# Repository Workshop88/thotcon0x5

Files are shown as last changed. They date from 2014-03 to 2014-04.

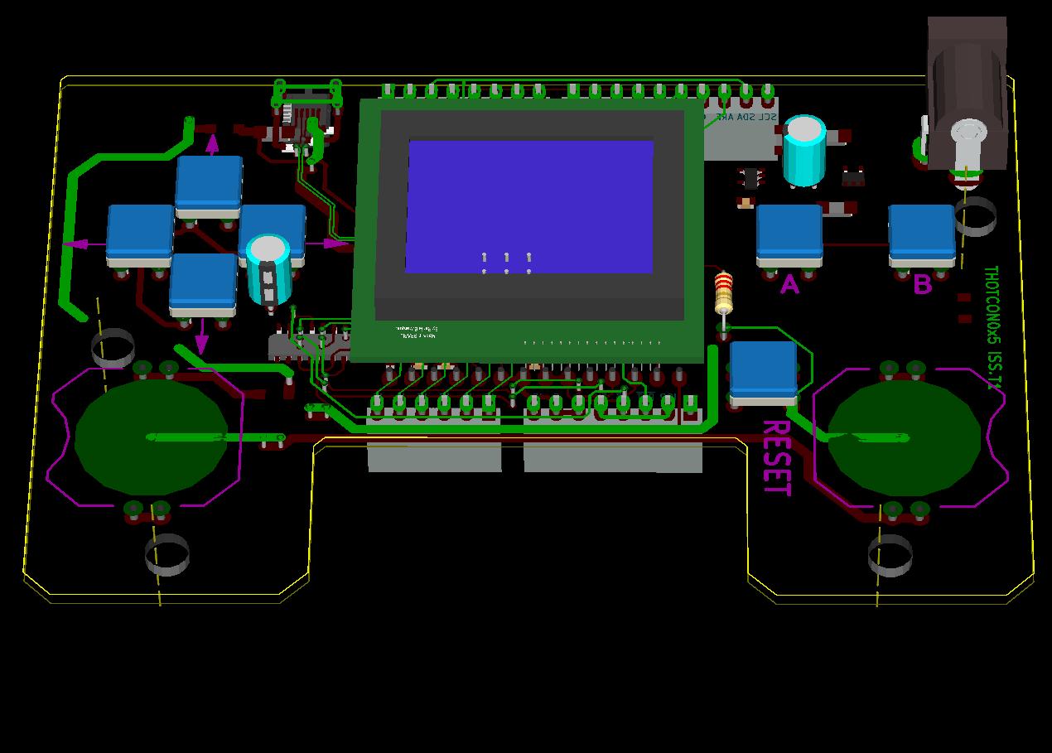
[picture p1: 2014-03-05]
hardware/attic/iss_T1/release/thotcon_user_perspective.jpg

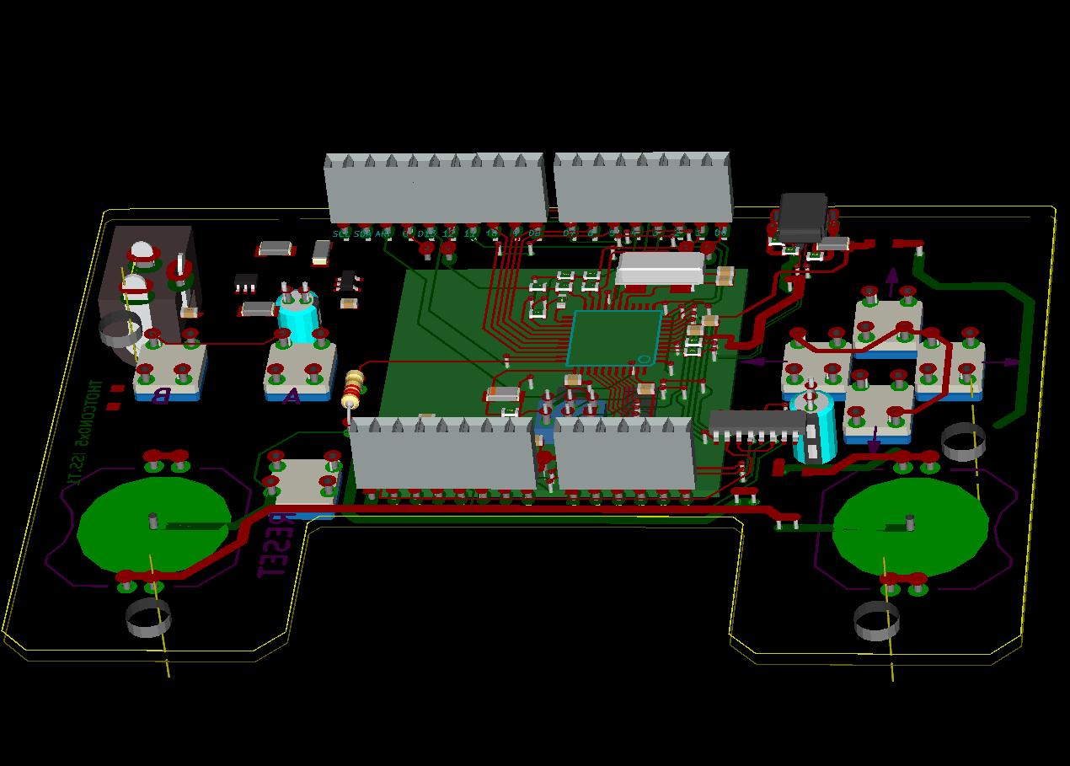
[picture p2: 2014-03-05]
hardware/attic/iss_T1/release/thotcon_perspective_bottom.jpg

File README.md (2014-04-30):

Thotcon 0x5 badges.

Basics:
* Replace ARDUINO_ROOT/hardware/arduino/variants/leonardo/pins_arduino.h with libraries/pins_arduino.h (back up the existing one)
* Replace ARDUINO_ROOT/hardware/arduino/boards.txt with the one from this repo.
* To program via USB, you need the actual Leonardo or LilyPadUSB bootloader.  To install that, you'll need to use some kind of AVRISP.  This is a good place to start: http://letsmakerobots.com/content/make-arduino-isp-programmer

More:
* The schematics are under hardware/development/iss_p1/release

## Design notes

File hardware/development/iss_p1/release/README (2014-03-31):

The files in this directory are in PDF format, and are provided as
a convenience. In the event of a discrepancy, the gerber files in the
"fab" directory will govern.

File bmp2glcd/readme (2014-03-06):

bmp2glcd - Bitmap to GLCD bitmap ver 1.01 by S.Varjo 2008

To create binary file simply invoke make. 

Usage: bmp2glcd <image.bmp> <options>
	-h <height>	target image height in pixels
	-w <width>	target image width in pixels
	-v	verbose mode
	-pgm	create header with __attribute__ ((progmem)) for AVR
	-pic30  create header whith __attribute__((space(auto_psv))) for PIC30
	-glcdlib create header for use with Arduino glcd library

This program converts a bitmap to binary bitmap (black and white) with 8bit page
height that can be written directly to graphical lcd display. A c-header file is
created where data bytes represent pixels in page columns rather than in lines.
The created bitmap is solely to see the result image in a simple way.

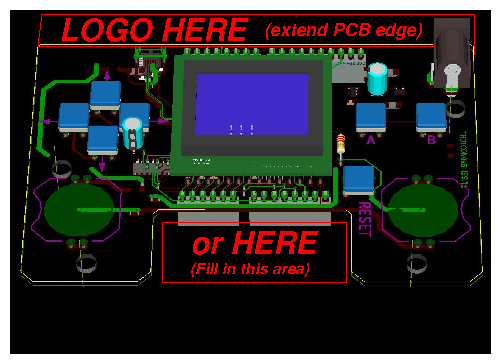
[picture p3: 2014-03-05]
hardware/attic/iss_T1/release/thotcon_label_view.png

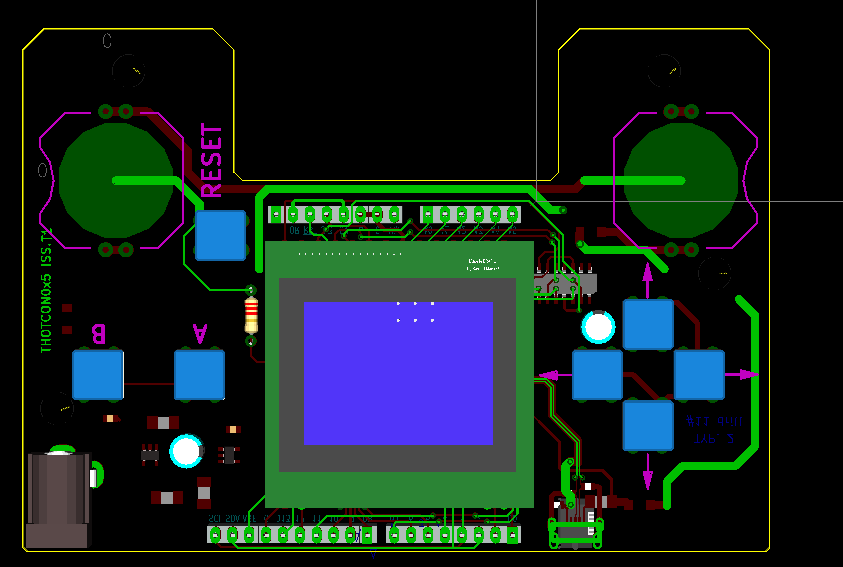
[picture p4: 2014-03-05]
hardware/attic/iss_T1/release/thotcon_0x5_display.png

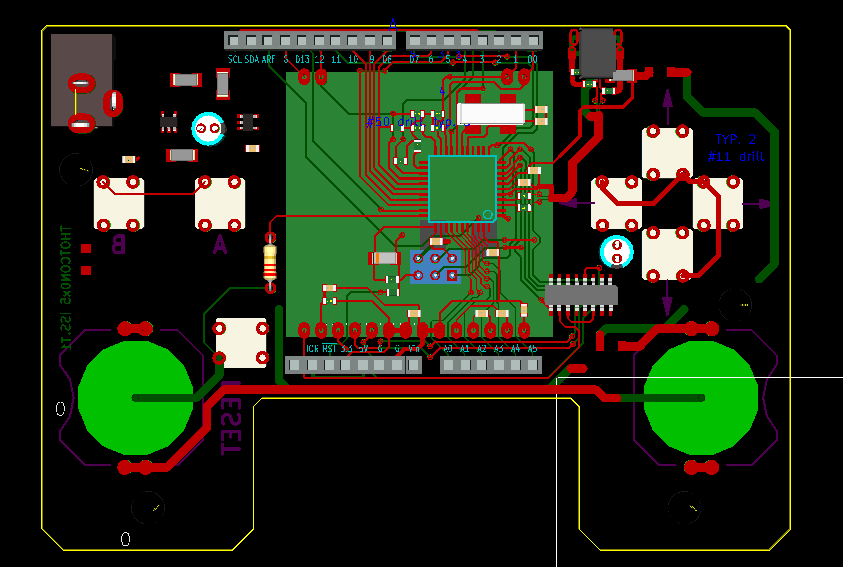
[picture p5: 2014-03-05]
hardware/attic/iss_T1/release/thotcon_0x5_bottom.png

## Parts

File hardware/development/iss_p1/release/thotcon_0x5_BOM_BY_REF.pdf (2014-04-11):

Sheet1
03/28/14 | ISSUE P1 | | PRINTED 032814 | | ISSUE P1 | | | ISSUE P1 | | ISSUE P1
REF. | VALUE | QTY. | DESCRIPTION | MFR | MFR_PN | PRICE EA @100 | EXT. | ASSY_STATUS | VENDOR 1 | VENDOR 2 | NOTES
B1,B2 | BATTERY | 2 | HOLDER BATT 2032 | LINX | BAT-HLD-001-THM | 0.27 | 0.54 | Y | Mous 712-BAT-HLD-001-THM | Digi BAT-HLD-001-THM-ND | Thru Hole
C2,C9,C11,C14,C15,C16 | 1 uF | 6 | CAP CER 0603 1uF 10% X7R | MURATA | GRM188R71E105KA12 | 0.061 | 0.366 | Y | TTI GRM188R71E105KA12 | Digi 490-5307-1-ND | 25 Volt
C3,C5,C7 | 4.7 uF | 3 | CAP CER 1206 4.7u 10% X7R | MURATA | GRM31CR71E475KA88L | 0.11 | 0.33 | Y | Mous 81-GRM31CR71E475KA88 | Digi 490-1809-1-ND | 25 Volt
C4,C6 | .01 uF | 2 | CAP CER 0603 .01 10% X7R | MURATA | GRM188R71C103KA01D | 0.02 | 0.04 | Y | Mous 81-GRM18R71C103KA01D | Digi 490-1525-1-ND | 16 Volt
C8,C17,C18,C19,C20 | .1 uF | 5 | CAP CER 0603 .1 10% X7R | MURATA | GRM188R71H104KA93 | 0.07 | 0.35 | Y | Mous 81-GRM188R71H104KA93 | Digi 490-1519-1-ND | 50 Volt
C12,C13 | 18 pF | 2 | CAP CER 0603 18 5% NPO | MURATA | GRM1885C1H180JA01D | 0.01 | 0.02 | Y | Mous 81-GRM39C180J50 | Digi 490-1409-1-ND | 25 Volt
D2,D4,D5 | MBR0530 | 3 | DIODE SCHTKY 20V | ON SEMI | MBR0530T1G | 0.06 | 0.18 | Y | NWK 83H7280 | Mous 863-MBR0530T1G
D6 | S01575 | 1 | DIODE SIG 75V SMD1206 | BOURNS | CD1206-S01575 | 0.04 | 0.04 | Y | Mous 652-CD1206-S01575 | Digi CD1206-S01575CT-ND
DS1 | LC DISPLAY | 1 | LCD GRPHIC 102x64 WHT | ELECT ASMBYS | DOGS102W-6 | 6.73 | 6.73 | Y | Mous 790-EADOGS102W-6
DS2 | “PARTY” | 1 | DIODE LED RED 1206 REV | KINGBRIGHT | APTR3216SURCK | 0.09 | 0.09 | Y | | Digi 754-1173-1-ND
F1 | .5 A | 1 | FUSE POLY 1206 .5A 15V | Littelfuse | 1206L050/15YR | 0.21 | 0.21 | Y | Mous 576-1206L050/15YR | Digi F3733CT-ND
J6 | USB_IN | 1 | CONN USB MICRO B THM | TE CONN / AMP | 2040002-1 | 1.29 | 1.29 | Y | Mous 604-APTR3216SURCK | Digi A108263CT-ND | Thru hole
R1 | 1K | 1 | RES CER 0603 1K 5% 1/10 | PANASONIC | ERJ3GEYJ102V | 0.006 | 0.01 | Y | Mous 667-ERJ-3GEYJ102V | Digi P1.0KGCT-ND
R2,R3 | 5V | 2 | VRSTR ESD 0603 LO-CAP | BOURNS | CG0603MLC-05E | 0.09 | 0.18 | Y | Mous 652-CG0603MLC-05E | Digi CG0603MLC-05ECT-ND
R4,R5 | 22 | 2 | RES CER 0603 22 5% 1/10 | PANASONIC | ERJ-3GEYJ220V | 0.003 | 0.005 | Y | Mous 667-ERJ-3GEYJ220V | Digi P220GCT-ND
R6,R16 | 120 | 2 | RES CER 0603 120 5% 1/10 | PANASONIC | ERJ-3GEYJ121V | 0.003 | 0.005 | Y | Mous 667-ERJ-3GEYJ121V | Digi P120GCT-ND
R7-R13 | 10K | 7 | RES CER 0603 10K 5% 1/10 | PANASONIC | ERJ-3GEYJ103V | 0.003 | 0.018 | Y | Mous 667-ERJ-3GEYJ103V | Digi P10KGCT-ND
R14 | 2.2K | 1 | RES CF AXIAL 2.2K 5% 1/8 | STACKPOLE | CF18JT2K20 | 0.02 | 0.02 | Y | Digi CF18JT2K20CT-ND
S1,S2 | RED | 2 | SW PB N.O. RED | TE CONN / AMP | 1825910-7 | 0.08 | 0.16 | Y | | Digi 450-1804-ND | RED
S3,S4,S5,S6,S7 | BLACK | 5 | SW PB N.O. BLACK | TE CONN / AMP | FSM4JH | 0.08 | 0.40 | Y | Mous 506-FSM4JH | Digi 450-1650-ND | BLACK
U1 | ATMEGA32U4 | 1 | IC MICROP AVR | ATMEL | ATMEGA32U4-AU | 3.67 | 3.67 | Y | NWK 68T2838 | Digi 535-11697-1-ND
U2 | 5V | 1 | IC VREG LDO 5V SOT23 | TI | LP2985-50DBVR | 0.23 | 0.23 | Y | Mous 595-LP2985-50DBVR | Digi 296-20717-1-ND
U3 | 3.3V | 1 | IC VREG LDO 3.3V SOT23 | TI | LP2985-33DBVR | 0.28 | 0.28 | Y | Mous 595-LP2985-33DBVR | Digi 296-18476-1-ND
U4 | MC14050 | 1 | IC LVL SHFTR HEX SOIC | ON SEMI | MC14050BDR2G | 0.15 | 0.15 | Y | Mous 863-MC14050BDR2G | Digi MC14050BDR2GOSCT-ND
Y1 | 8.000 MHz | 1 | XTAL 8 MHZ SMT | ABRACON | ABC2-8.000MHZ-4-T | 1.13 | 1.13 | Y | Mous 815-ABMM-16-B2-T | Digi 535-9155-1-ND
Z1,Z2 | 300 | 2 | IND FE 300 OHM | TDK | MMZ1608-B-301C | 0.02 | 0.04 | Y | Mous 810-MMZ1608B301C | Digi 445-2165-1-ND
| | | | | | SUB-TOTAL | 16.481

### NON-ITEMIZED

B1, B2 | CR2032 | 2 | BATTERY LI COIN 2032 | PANASONIC | CR2032 | 0.16 | 0.32 | Y
BOARD, PC | --- | 1 | DOUBLE SIDE | ****** ESTIMATED COST ******* | 4.00 | 4.00 | Y
| | | | | | PRODUCTION TOTAL | 20.80

### ADD-ON KIT

C1,C10 | 10 uF | 2 | CAP LYTIC RADIAL 10uF 20% | PANASONIC | ECEA1VKS100 | 0.06 | 0.12 | DO NOT PLACE | Mous 667-ECE-A1VKS100 | Digi P980-ND | 35 Volt
J1,J3 | 8 PIN | 2 | SOCKET STRP .1 1X8 | HARWIN | M20-7820842 | 0.55 | 1.10 | DO NOT PLACE | Mous 855-M20-7820842 | Digi 952-1823-ND
J2 | 6 PIN | 1 | SOCKET STRP .1 1X6 | HARWIN | M20-7820646 | 0.48 | 0.48 | DO NOT PLACE | Mous 855-M20-7820646 | Digi 952-1809-ND
J4 | 10PIN | 1 | SOCKET STRP .1 1X10 | HARWIN | M20-7821042 | 1.10 | 1.10 | DO NOT PLACE | Mous 855-M20-7821042 | Digi 952-1846-ND
J5 | EXT_POWER | 1 | JACK 2MM TAPER PIN | CUI | PJ-102A | 0.45 | 0.45 | DO NOT PLACE | Digi CP-102A-ND | FUTURE PJ-102A | Suffix H OK
| | | | | | Add-on SUBTOTAL | 3.25
| | | | | | WS88 BADGE TOTAL | 24.06

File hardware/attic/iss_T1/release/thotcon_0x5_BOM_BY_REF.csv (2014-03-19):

ref | value | Field1 | Field2 | Field3 | Field4 | Field5 | Field6 | Field7 | Field8 | Item count
B1,B2 | CR2032 | HOLDER BATT 2032 | LINX | BAT-HLD-001-THM | 0.27 | Y | Mous 712-BAT-HLD-001-THM | Digi BAT-HLD-001-THM-ND | Thru Hole | 2
C1 | 10 uF | CAP LYTIC RADIAL 10uF 20% | PANASONIC | ECEA1VKA100 | 0.11 | DO NOT PLACE | Mous 667-ECE-A1VKA100 | Digi P818-ND | 35 Volt | 1
C2 | 1 uF | CAP CER 0603 1uF 10% X7R | MURATA | GRM188R71E105KA12 | 0.061 | Y | TTI GRM188R71E105KA12 | Digi 490-5307-1-ND | 25 Volt | 1
C3 | 4.7 uF | CAP CER 1206 4.7u 10% X7R | MURATA | GRM31CR71E475KA88L | 0.11 | Y | Mous 81-GRM31CR71E475KA88 | Digi 490-1809-1-ND | 25 Volt | 1
C4 | .01 uF | CAP CER 0603 .01 10% X7R | MURATA | GRM188R71C103KA01D | 0.02 | Y | Mous 81-GRM18R71C103KA01D | Digi 490-1525-1-ND | 16 Volt | 1
C5 | 4.7 uF | CAP CER 1206 4.7u 10% X7R | MURATA | GRM31CR71E475KA88L | 0.11 | Y | Mous 81-GRM31CR71E475KA88 | Digi 490-1809-1-ND | 25 Volt | 1
C6 | .01 uF | CAP CER 0603 .01 10% X7R | MURATA | GRM188R71C103KA01D | 0.02 | Y | Mous 81-GRM18R71C103KA01D | Digi 490-1525-1-ND | 16 Volt | 1
C7 | 4.7 uF | CAP CER 1206 4.7u 10% X7R | MURATA | GRM31CR71E475KA88L | 0.11 | Y | Mous 81-GRM31CR71E475KA88 | Digi 490-1809-1-ND | 25 Volt | 1
C8 | .1 uF | CAP CER 0603 .1 10% X7R | MURATA | GRM188R71H104KA93 | 0.07 | Y | Mous 81-GRM188R71H104KA93 | Digi 490-1519-1-ND | 50 Volt | 1
C9 | 1 uF | CAP CER 0603 1uF 10% X7R | MURATA | GRM188R71E105KA12 | 0.061 | Y | TTI GRM188R71E105KA12 | Digi 490-5307-1-ND | 25 Volt | 1
C10 | 10 uF | CAP LYTIC RADIAL 10uF 20% | PANASONIC | ECEA1VKA100 | 0.11 | Y | Mous 667-ECE-A1VKA100 | Digi P818-ND | 35 Volt | 1
C11 | 1 uF | CAP CER 0603 1uF 10% X7R | MURATA | GRM188R71E105KA12 | 0.061 | Y | TTI GRM188R71E105KA12 | Digi 490-5307-1-ND | 25 Volt | 1
C12,C13 | 18 pF | CAP CER 0603 18 5% NPO | MURATA | GRM1885C1H180JA01D | 0.01 | Y | Mous 81-GRM39C180J50 | Digi 490-1409-1-ND | 25 Volt | 2
C14..C16 | 1 uF | CAP CER 0603 1uF 10% X7R | MURATA | GRM188R71E105KA12 | 0.061 | Y | TTI GRM188R71E105KA12 | Digi 490-5307-1-ND | 25 Volt | 3
C17..C20 | .1 uF | CAP CER 0603 .1 10% X7R | MURATA | GRM188R71H104KA93 | 0.07 | Y | Mous 81-GRM188R71H104KA93 | Digi 490-1519-1-ND | 50 Volt | 4
D2..D5 | MBR0530 | DIOD SCHTKY 20V | ON SEMI | MBR0530T1G | 0.06 | Y | NWK 83H7280 | Mous 863-MBR0530T1G |  | 3
D6 | S01575 | DIODE SIG 75V SMD1206 | BOURNS | CD1206-S01575 | 0.04 | Y | Mous 652-CD1206-S01575 | Digi CD1206-S01575CT-ND |  | 1
DS1 | EA_DOGS102 | LCD GRPHIC 102x64 WHT | ELECT ASSMBYS | DOGS102W-6 | 6.73 | Y | Mous 790-EADOGS102W-6 |  |  | 1
F1 | .5 A | FUSE POLY 1206 .5A 15V | Littelfuse | 1206L050/15YR | 0.21 | Y | Mouser 576-1206L050/15YR | Digikey F3733CT-ND |  | 1
J1 | POWER | SOCKET STRP .1 1X8 | HARWIN | M20-7820842 | 0.55 | DO NOT PLACE | Mous 855-M20-7820842 | Digi 952-1823-ND |  | 1
J2 | ANALOG | SOCKET STRP .1 1X6 | HARWIN | M20-7820646 | 0.48 | DO NOT PLACE | Mous 855-M20-7820646 | Digi 952-1809-ND |  | 1
J3 | DIGITAL_0 | SOCKET STRP .1 1X8 | HARWIN | M20-7820842 | 0.55 | DO NOT PLACE | Mous 855-M20-7820842 | Digi 952-1823-ND |  | 1
J4 | DIGITAL_1 | SOCKET STRP .1 1X10 | HARWIN | M20-7821042 | 1.104 | DO NOT PLACE | Mous 855-M20-7821042 | Digi 952-1846-ND |  | 1
J5 | EXT_POWER | JACK 2MM TAPER PIN | CUI | PJ-102A | 0.45 | DO NOT PLACE | Digi CP-102A-ND | FUTURE PJ-102A | Suffix H OK | 1
J6 | USB_IN | CONN USB MICRO B THM | TE | 2040002-1 | 1.99 | Y | Digi A108263CT-ND |  |  | 1
MH1..MH4 | TOOLING | TOOLING | P/O PCB |  |  |  |  |  |  | 4
P2 | ICSP | TEST PORT | P/O PCB |  |  |  |  |  |  | 1
R2,R3 | 5V | VRSTR ESD 0603 LO-CAP | BOURNS | CG0603MLC-05E | 0.09 | Y | Mous 652-CG0603MLC-05E | Digi CG0603MLC-05ECT-ND |  | 2
R4,R5 | 22 | RES CER 0603 22 5% 1/10 | PANASONIC | ERJ-3GEYJ220V | 0.003 | Y | Mous 667-ERJ-3GEYJ220V | Digi P220GCT-ND |  | 2
R6 | 120 | RES CER 0603 120 5% 1/10 | PANASONIC | ERJ-3GEYJ121V | 0.003 | Y | Mous 667-ERJ-3GEYJ121V | Digi P120GCT-ND |  | 1
R7..R13 | 10K | RES CER 0603 10K 5% 1/10 | PANASONIC | ERJ-3GEYJ103V | 0.003 | Y | Mous 667-ERJ-3GEYJ103V | Digi P10KGCT-ND |  | 7
R14 | 2.2K | RES CF AXIAL 2.2K 5% 1/8 | STACKPOLE | CF18JT2K20 | 0.02 | DO NOT PLACE | Digi CF18JT2K20CT-ND |  |  | 1
R16 | 10K | RES CER 0603 10K 5% 1/10 | PANASONIC | ERJ-3GEYJ103V | 0.003 | Y | Mous 667-ERJ-3GEYJ103V | Digi P10KGCT-ND |  | 1
S1 | A | SW PB N.O. | OMRON | B3F-1000 | 0.35 | Y | Mous 653-B3F-1000 | Digi SW400-ND |  | 1
S2 | B | SW PB N.O. | OMRON | B3F-1000 | 0.35 | Y | Mous 653-B3F-1000 | Digi SW400-ND |  | 1
S3 | RST | SW PB N.O. | OMRON | B3F-1000 | 0.35 | Y | Mous 653-B3F-1000 | Digi SW400-ND |  | 1
S4 | UP | SW PB N.O. | OMRON | B3F-1000 | 0.35 | Y | Mous 653-B3F-1000 | Digi SW400-ND |  | 1
S5 | RGT | SW PB N.O. | OMRON | B3F-1000 | 0.35 | Y | Mous 653-B3F-1000 | Digi SW400-ND |  | 1
S6 | DWN | SW PB N.O. | OMRON | B3F-1000 | 0.35 | Y | Mous 653-B3F-1000 | Digi SW400-ND |  | 1
S7 | LFT | SW PB N.O. | OMRON | B3F-1000 | 0.35 | Y | Mous 653-B3F-1000 | Digi SW400-ND |  | 1
U1 | ATMEGA32U4 | IC MICROP AVR | ATMEL | ATMEGA32U4-AU | 3.96 | Y | NEWARK 68T2838 | Digi 535-11697-1-ND |  | 1
U2 | 5V | IC VREG LDO 5V SOT23 | TI | LP2985-50DBVR | 0.23 | Y | Mous 595-LP2985-50DBVR | Digi 296-20717-1-ND |  | 1
U3 | 3.3V | IC VREG LDO 3.3V SOT23 | TI | LP2985-33DBVR | 0.28 | Y | Mous 595-LP2985-33DBVR | Digi 296-18476-1-ND |  | 1
U4 | MC14050 | IC LVL SHFTR HEX SOIC | ON SEMI | MC14050BDR2G | 0.15 | Y | Mous 863-MC14050BDR2G | Digi MC14050BDR2GOSCT-ND |  | 1
Y1 | 8.000 MHz | XTAL 8 MHZ SMT | ABRACON | ABC2-8.000MHZ-4-T | 1.13 | Y | Mous 815-ABMM-16-B2-T | Digi 535-9155-1-ND |  | 1
Z1,Z2 | 300 | IND FE 300 OHM | TDK | MMZ1608-B-301C | 0.02 | Y | Mous 810-MMZ1608B301C | Digi 445-2165-1-ND |  | 2

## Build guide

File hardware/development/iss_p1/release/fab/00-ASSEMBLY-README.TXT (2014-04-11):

FILE:  00-ASSEMBLY-README.TXT 

April 11 2014 rev. P1

CHANGES:

    1.  Do not place white tape on "gold" and red boards.
    2.  Do not put white tape on DS1. Delete white tape from BOM.
    3.  (4a) Do not remove manufacturer stickers from display.
    4.  ADD Note A, Red and black switches.

Project: "Thotcon0x5 Badge Project" - An electric name tag.

Customer: Workshop 88, Inc.
Engineer: Paul Reich <reichp@att.net> -- 630-924-7289.
Project Manager: Rudy Ristich <rudy@workshop88.com>

Client: Thotcon 0x5 Organizing Committee.

NOTES:

   A.  Place RED switches at S1 and S2.  Place BLACK switches at
       S3, S4, S5, S6, & S7. Failure to do is a visual defect.

   1.  Please advise ASAP as to the suitability of the enclosed
       files, particularly the centroid file (thotcon_0x5-all.pos),
       should any file conversions be required.
       
   2.  A quantity of parts sufficient to assemble a minimum of 850
       units will be delivered for assembly.
       
       Over-runs, scrap, and leftover material must be returned.
       Please return unpopulated PCBs and panels as well.

   3.  Manufacture each of the following colors as follows:

        SOLDER MASK         SILKSCREEN        Quantity
   
       Gloss "gold"           BLACK           8 minimum
       Gloss red              BLACK          40   "
       Gloss blue             WHITE          40   "
       Gloss green            WHITE         128   "
       Flat black             WHITE         608   "
                                            ____________
                              GRAND TOTAL   824 minimum

   4.  DS1 - Glass display:
           Glass display DS1 must be fixtured such that the under-
           side of the display is spaced .04" - .07" above the PCB
           surface.  Failure to do so is a DEFECT that will leave
           the displays susceptible to mechanical and thermal stress
           and breakage.

   5.  There are a several unused components on each assembly. These
       components are designated "DO NOT PLACE" or "P/O PCB" on the
       bill of material. Holes for "DO NOT PLACE" components must
       remain free of solder.

   6.  Battery holders must be positioned with opening (cutout) as
       shown on the silkscreen.
       
   7.  Build ALL GOLD and RED panels FIRST. Build ALL GREEN and BLUE
       panels next. Build the BLACK panels LAST. These panels are
       the most numerous. Shortfalls here can be accommodated more
       readily.
       
   8.  Finished goods must be packaged in a manner sufficient to
       protect against ESD hazards & breakage of the (glass) display
       unit. Antistat bags or antistat bubble wrap are acceptable.
       Like colors must be packaged or grouped together. 
       
   9.  Customer will install batteries and program units.

  10.  Completed units and other materials, as noted in (2) and (3)
       will be retrieved by the customer (or his agent) at your Elk
       Grove Village location.

********************************************************************

           -----------  FILE MANIFEST  ------------------

File name                                      Description
------------------------------------------------------------------
00-ASSEMBLY-README.1ST                    This file

thotcon_0x5-all.pos                       SMD pick and place file.
thotcon_0x5-F_Paste.gtp                   SMD side paste mask, Gerber
thotcon_0x5-B_SilkS-MIRROR.pdf            Through-hole silk, PDF (mirrored)
thotcon_0x5-Dwgs_User.pdf                 PCB Fab/Assembly dwg, PDF.
thotcon_0x5-F_SilkS.pdf                   SMD-side silkscreen PDF

REFERENCE:

File name                                      Description
----------------------------------------------------------------------
thotcon_0x5_SCHEM-A.pdf                  "A" size schematic, PDF format
thotcon_0x5_SCHEM-B.pdf                  "B" size (11x17) schematic, PDF
thotcon_0x5_BOM_BY_REF.pdf                Bill of material, PDF
thotcon_0x5-drl.rpt                       Drill report, text

thotcon_0x5-F_copper.pdf                  Front copper, PDF
thotcon_0x5-B_copper.pdf                  Back copper, PDF

thotcon_0x5-F_Mask.pdf                    Front mask, PDF
thotcon_0x5-B_Mask.pdf                    Back mask, PDF

04-01-2014 Thotcon0X5 Issue P1 release

EOF

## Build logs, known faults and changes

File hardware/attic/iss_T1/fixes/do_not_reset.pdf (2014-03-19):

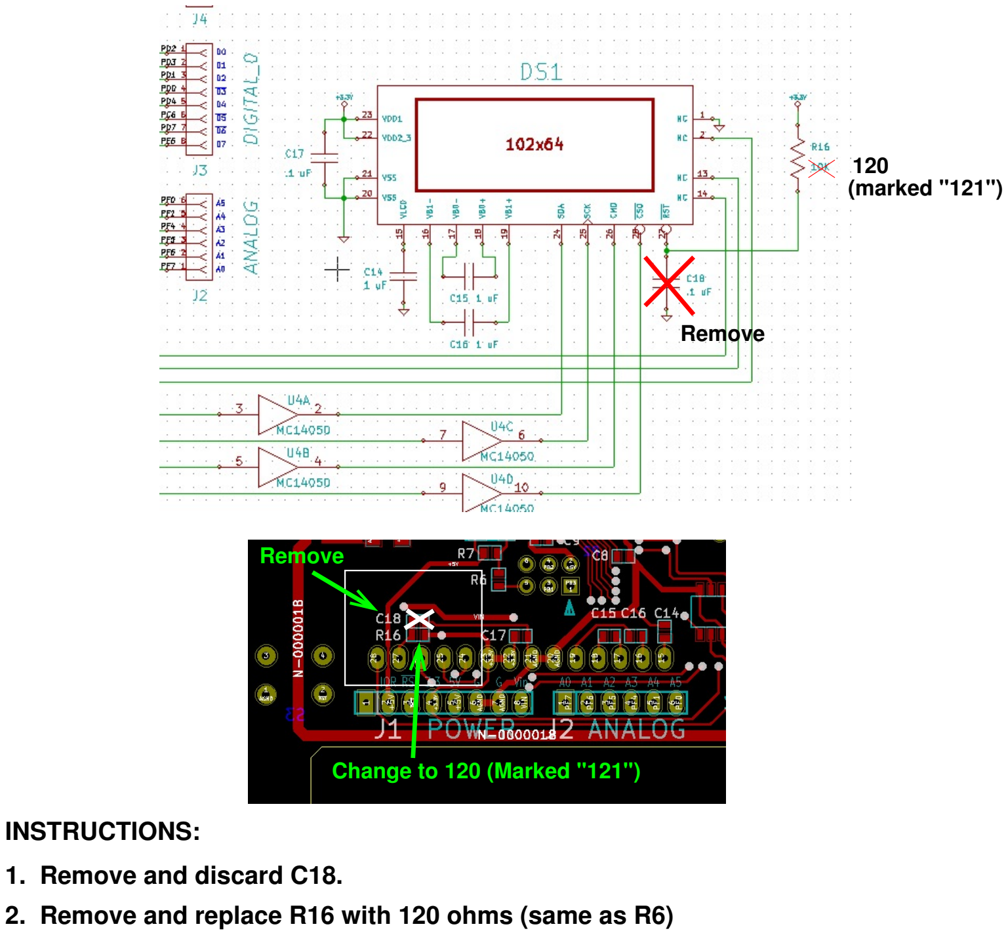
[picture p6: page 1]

120
(marked "121")

Remove

Remove

Change to 120 (Marked "121")

1. Remove and discard C18.

INSTRUCTIONS:

### 2. Remove and replace R16 with 120 ohms (same as R6)

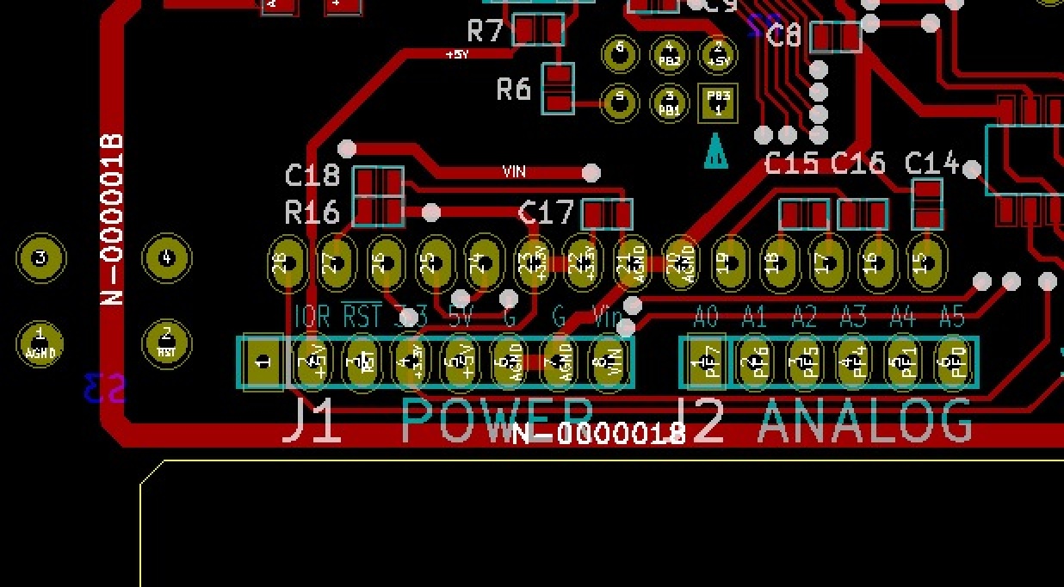
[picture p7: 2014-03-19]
hardware/attic/iss_T1/fixes/reset_3.jpg

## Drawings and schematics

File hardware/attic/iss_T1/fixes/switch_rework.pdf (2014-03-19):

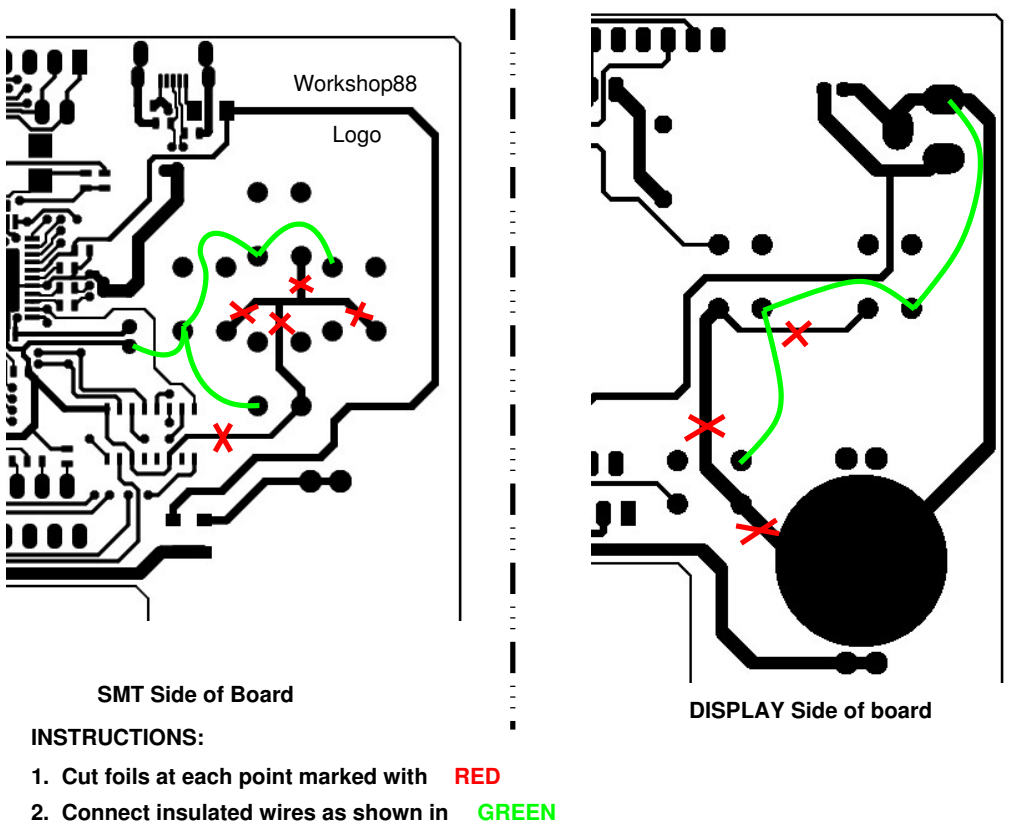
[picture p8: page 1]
Workshop88; Logo; GREEN; RED

SMT Side of Board

DISPLAY Side of board

INSTRUCTIONS:
1. Cut foils at each point marked with
2. Connect insulated wires as shown in

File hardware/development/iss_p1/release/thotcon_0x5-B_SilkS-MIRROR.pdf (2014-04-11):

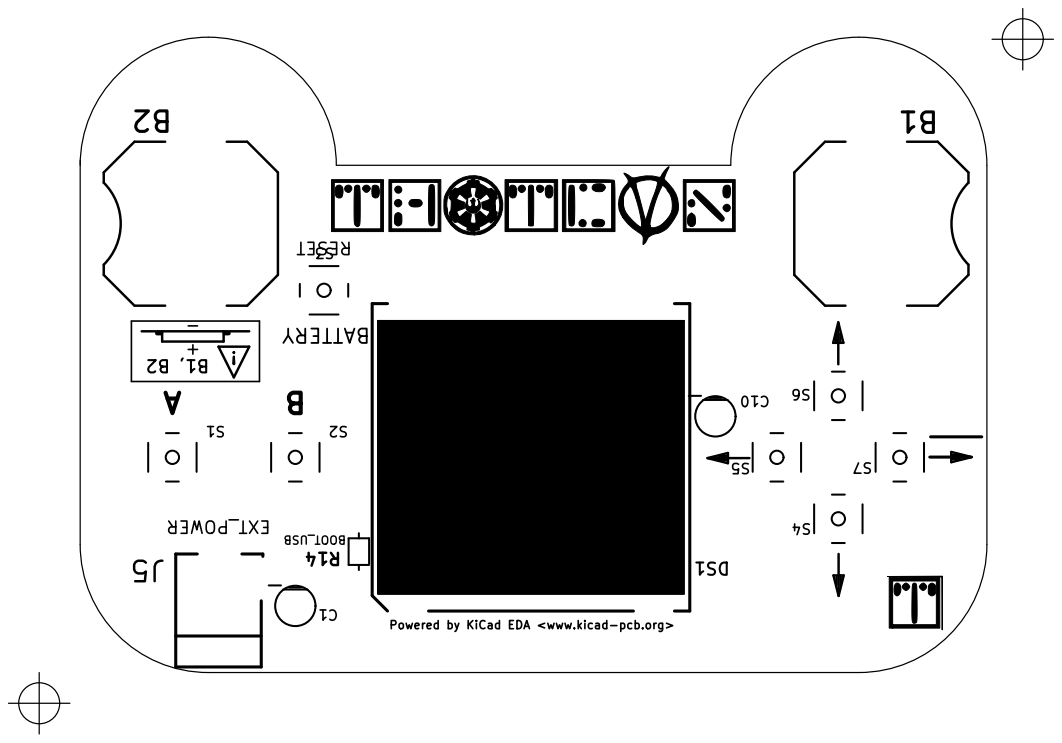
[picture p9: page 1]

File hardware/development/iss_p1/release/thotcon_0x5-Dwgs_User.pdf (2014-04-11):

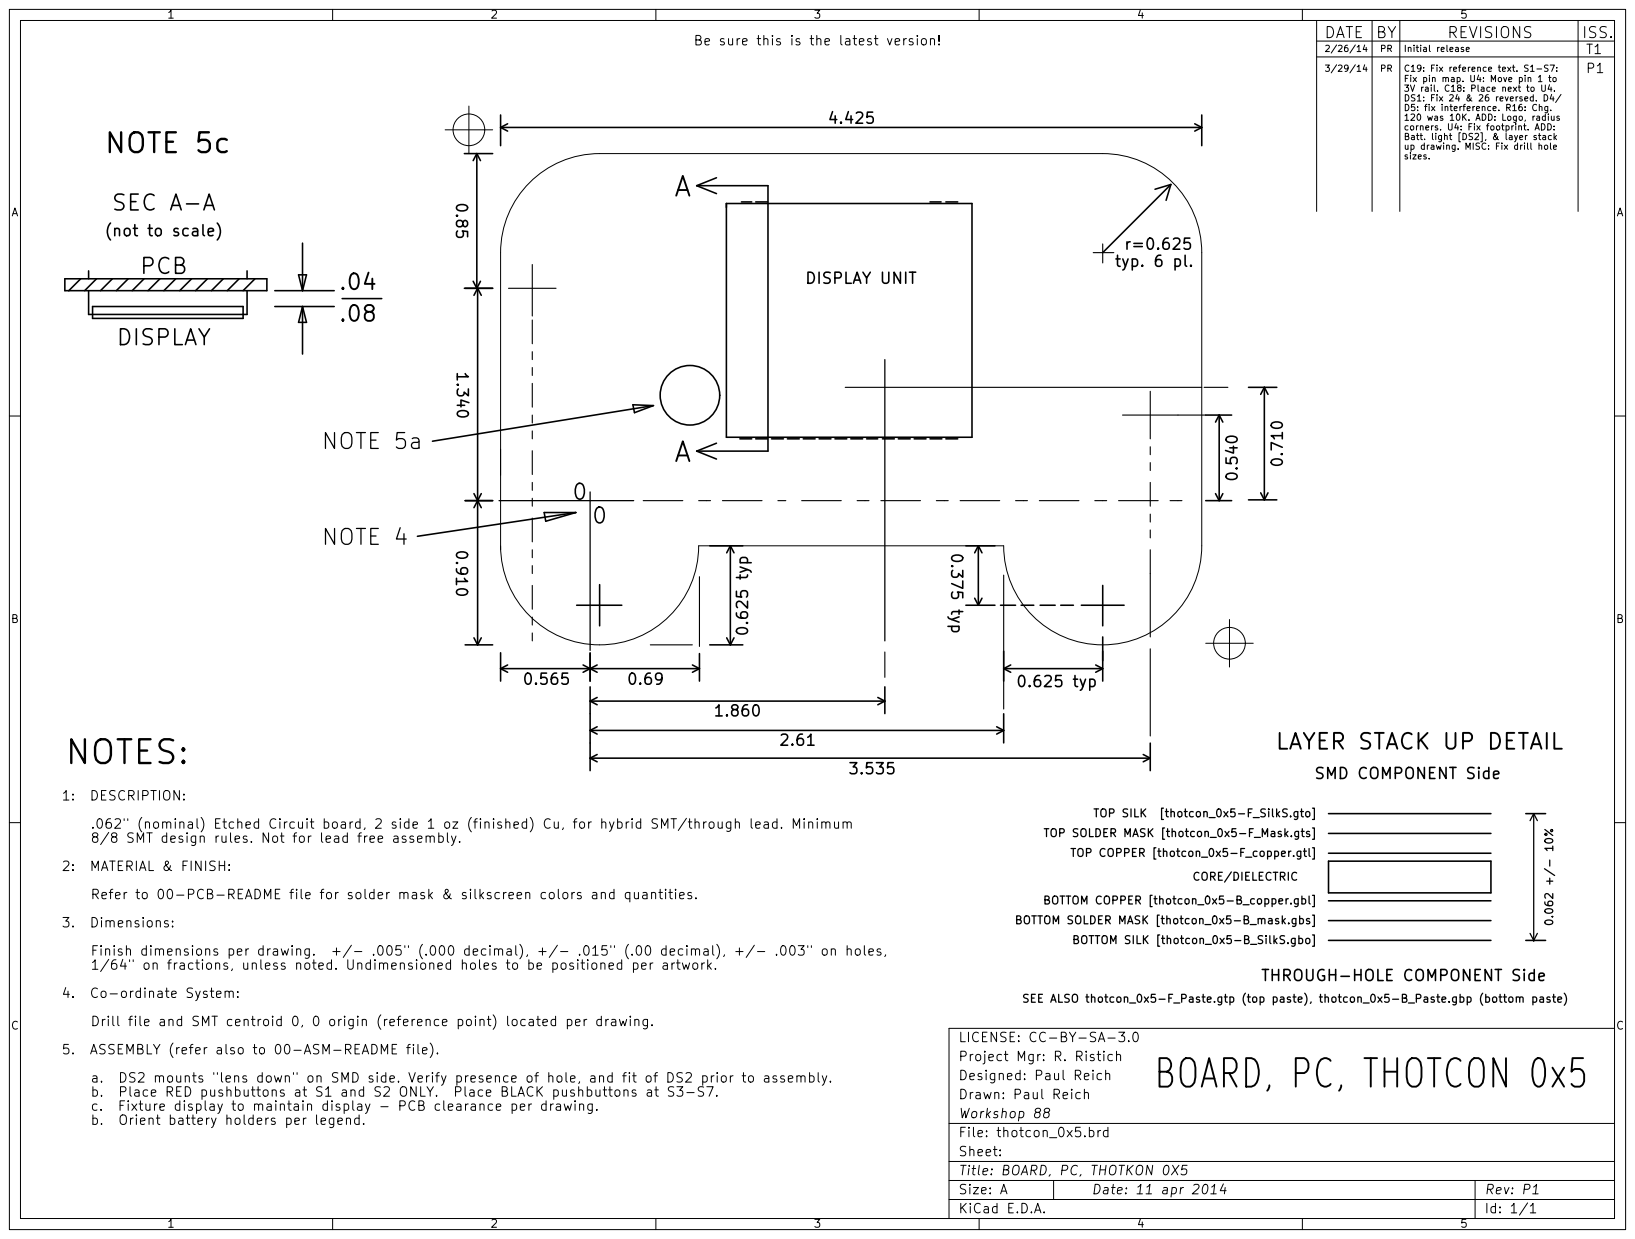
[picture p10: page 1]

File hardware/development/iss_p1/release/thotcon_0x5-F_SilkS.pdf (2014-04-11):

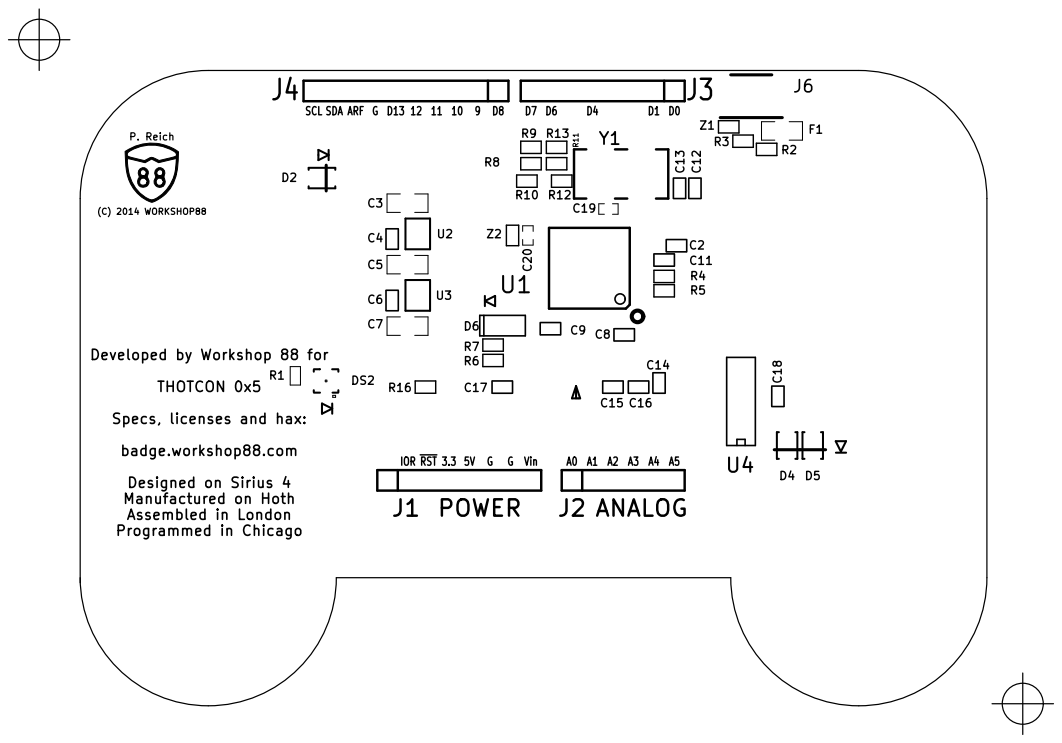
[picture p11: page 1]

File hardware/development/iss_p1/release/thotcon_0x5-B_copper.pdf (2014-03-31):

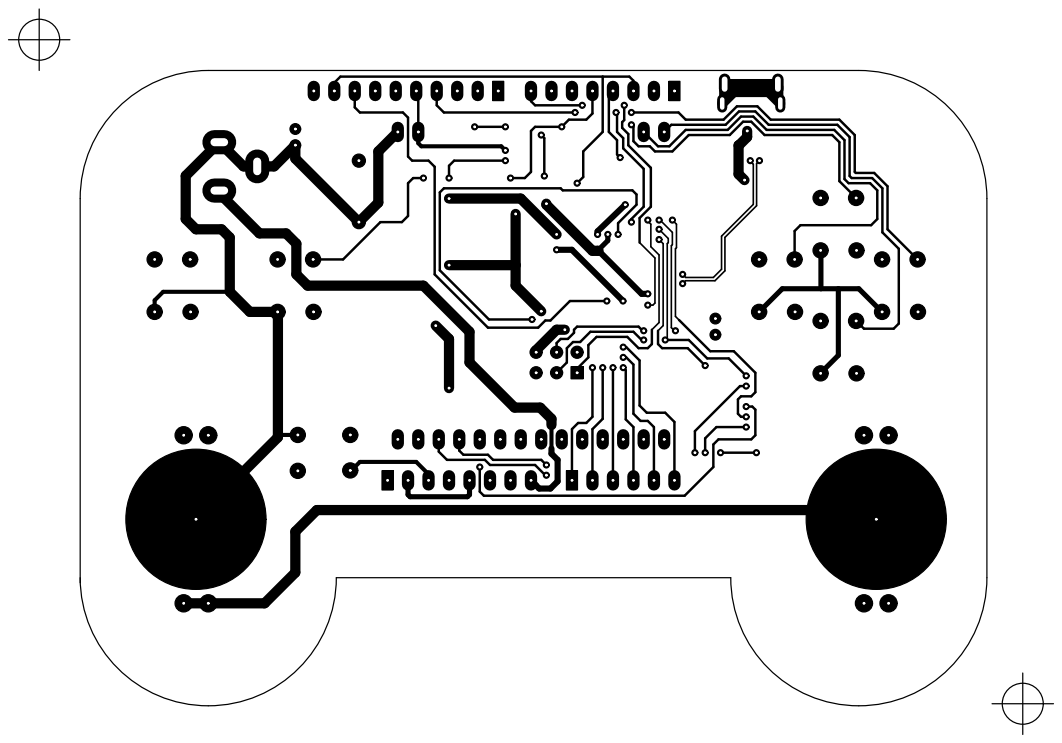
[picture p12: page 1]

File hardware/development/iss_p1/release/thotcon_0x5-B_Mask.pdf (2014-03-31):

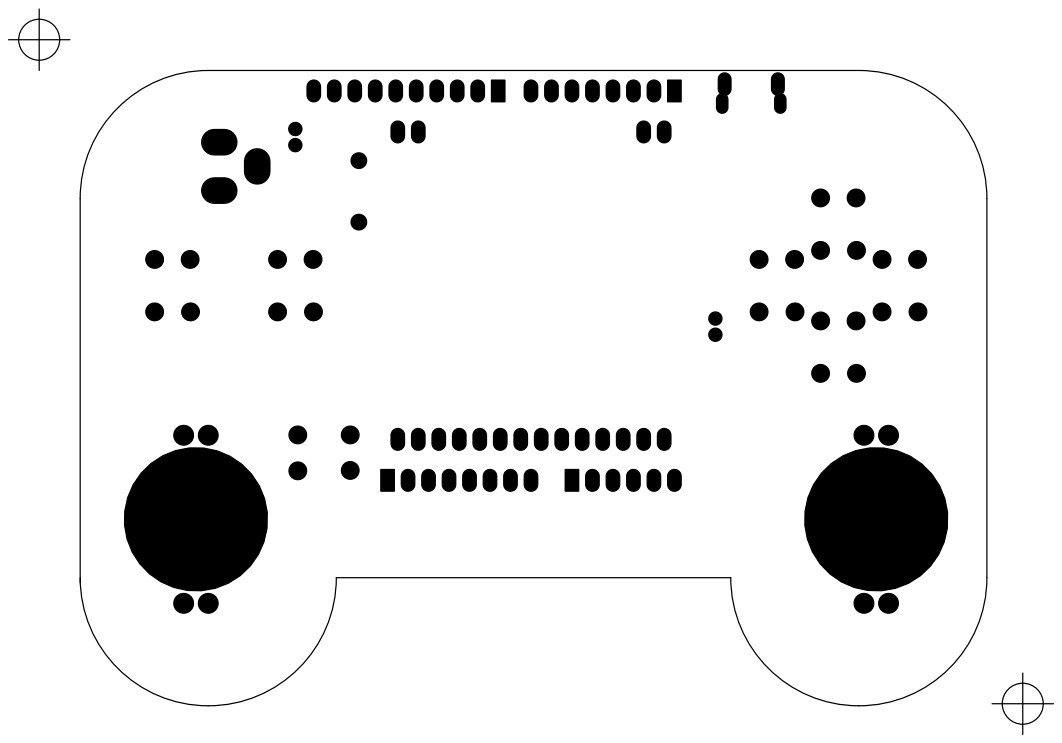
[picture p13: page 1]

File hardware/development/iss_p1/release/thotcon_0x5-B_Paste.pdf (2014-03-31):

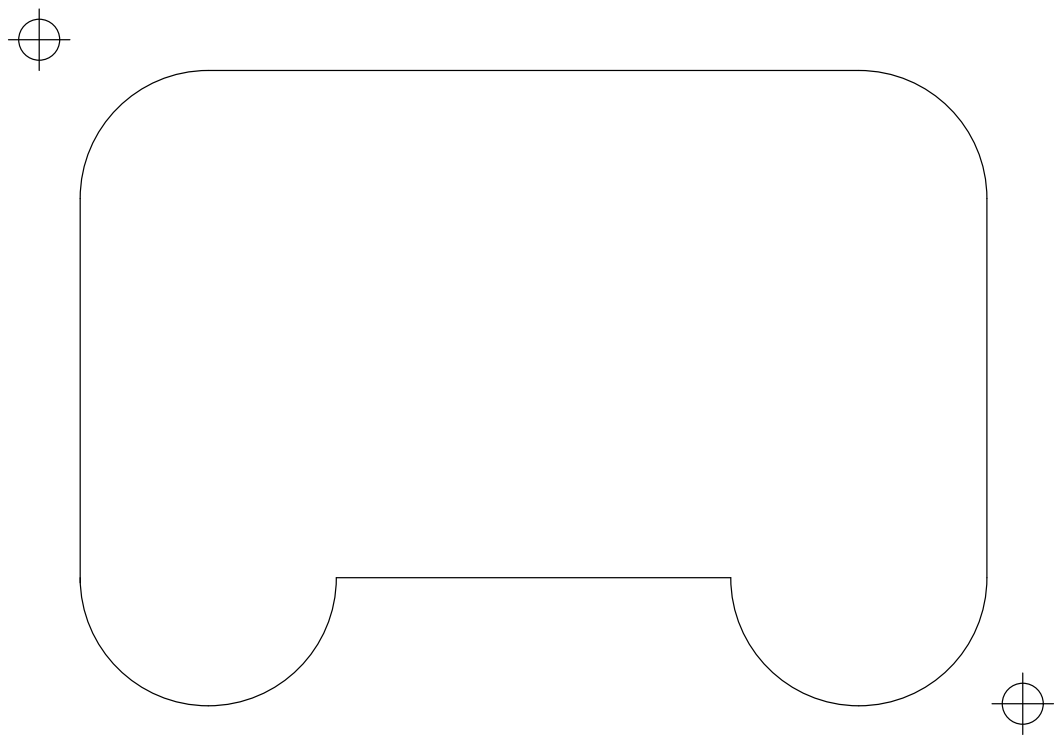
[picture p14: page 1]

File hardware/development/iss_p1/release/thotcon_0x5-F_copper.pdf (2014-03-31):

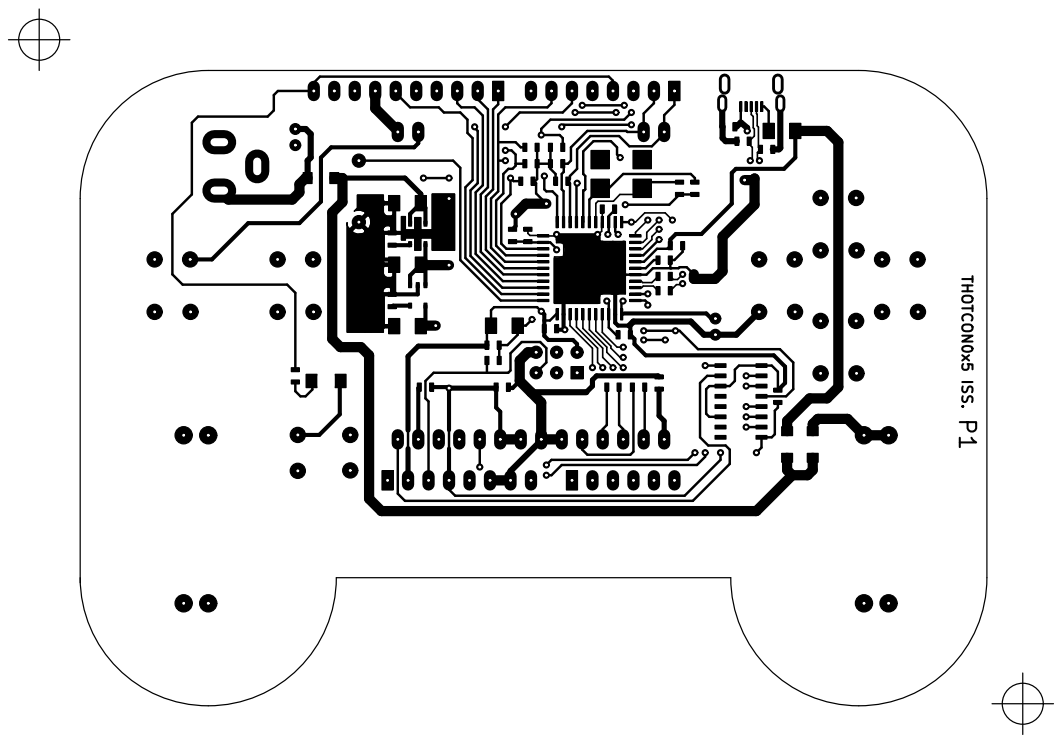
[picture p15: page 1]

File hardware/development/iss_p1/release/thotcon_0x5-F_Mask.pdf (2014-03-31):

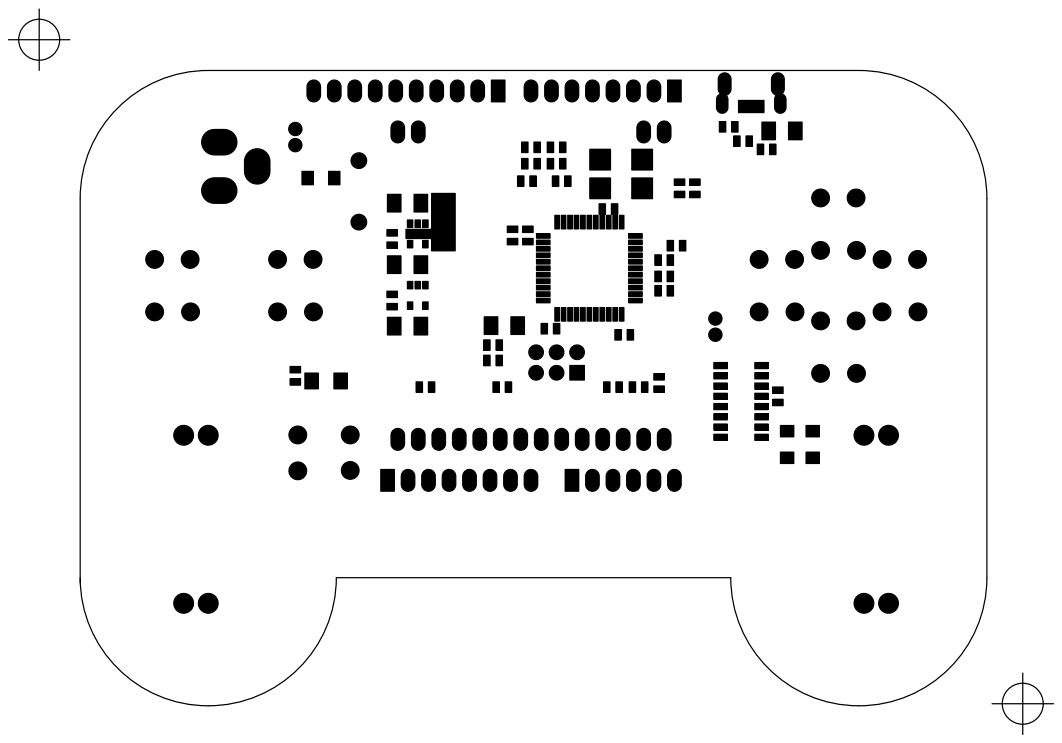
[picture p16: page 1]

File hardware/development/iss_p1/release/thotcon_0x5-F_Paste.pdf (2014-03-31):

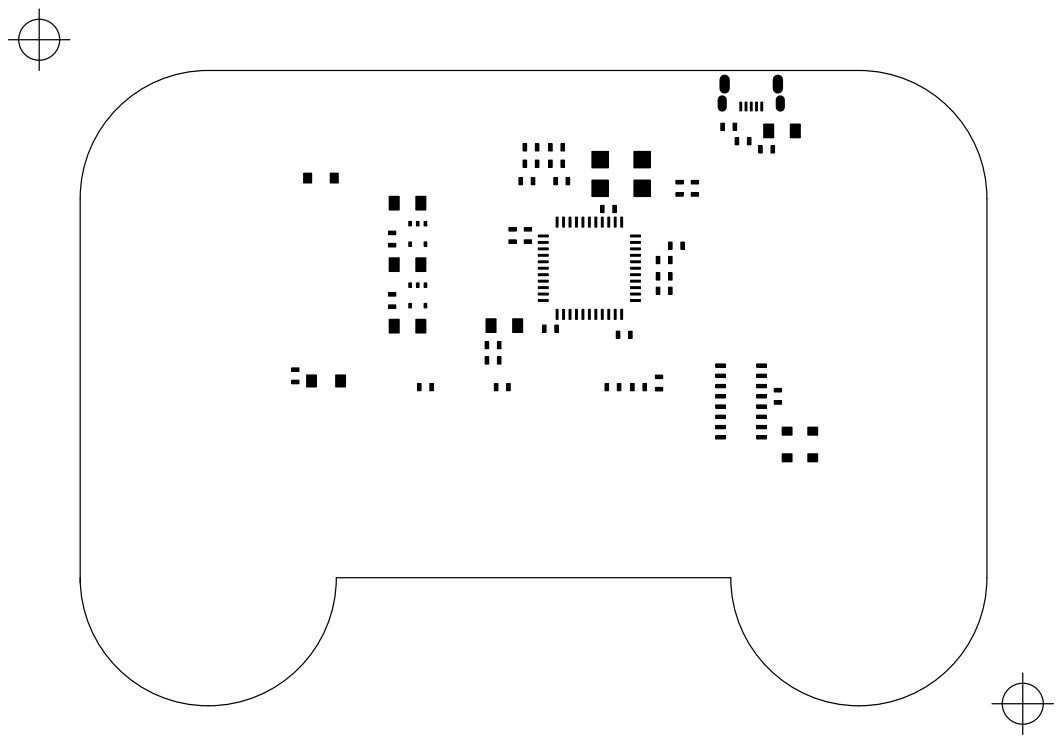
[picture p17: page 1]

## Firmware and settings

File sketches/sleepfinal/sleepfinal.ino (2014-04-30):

#include "U8glib.h"
#include <EEPROM.h>
#include <avr/sleep.h>

/*
U8GLIB_DOGS102 u8g(0,4); //teesy 
uint8_t uiKeyPrev = 17;
uint8_t uiKeyNext = 18;
uint8_t uiKeySelect = 14;
uint8_t uiKeyBack = 15;
uint8_t uiKeyRight = 20;
uint8_t uiKeyLeft = 19;
uint8_t led = 11;
*/


U8GLIB_DOGS102 u8g(17,11); //PROTO BOARD
//Leonardo based pin assignements must have updated pins_arduino.h for pin 30
uint8_t uiKeyPrev = 4;
uint8_t uiKeyNext = 0;
uint8_t uiKeySelect = 12;
uint8_t uiKeyBack = 6;
uint8_t uiKeyRight = 30;
uint8_t uiKeyLeft = 1;
uint8_t led = 3;


int isPlayer1 = 1;
char inputs[6] = { 0x04, 0x01, 0x00, 0x1E, 0x06, 0x0C };
char p1keys[7] = { 'W', 'A', 'S', 'D', 'Q', 'E', 'P' };
char p2keys[7] = { 'I', 'J', 'K', 'L', 'U', 'O', 'R' };

//#define DEBUG 1

/*select one badge type for compile*/

//#define HACKER_BADGE 1  //BLACK
//#define OPER_BADGE 1    //RED
//#define VOICE_BADGE 1     //BLUE
//#define VIP_BADGE 1     //GREEN
#define ROOT_BADGE 1     //GOLD

/* Tweak here for idle time, this determines when the badge draws and sleeps
   IDLE_MS should be left below 25 (~human reaction time).
   IDLE_SCALE should be (Target Time)/IDLE_MS
*/
#define IDLE_MS 15
#define IDLE_SCALE 2000
#define IDLE_BYTE 100

#define SCORE_BYTE 200

#define DISPLAY_WIDTH 102
#define L_FONT_HEIGHT 10
#define L_FONT_LENGTH 17 //printable characters per line


//Key States
#define KEY_NONE 0
#define KEY_PREV 1
#define KEY_NEXT 2
#define KEY_SELECT 3
#define KEY_BACK 4
#define KEYLEFT 5
#define KEYRIGHT 6

//Menu SM States
#define MAIN_STATE 255
#define GAME_STATE 0
#define SCHED_STATE 1
#define LINK_STATE 2
#define REG_STATE 3
#define HELP_STATE 4
#define TRACK_ONE_STATE (SCHED_STATE << 4)
#define TRACK_TWO_STATE (SCHED_STATE << 5)
#define LABS_STATE  (SCHED_STATE << 6)
#define VILLAGE_STATE (SCHED_STATE << 7)
#define PARTY_STATE 5

//menu global strings and consts for draw states and such
#define MENU_ITEMS 5
#define TRACK1_ITEMS 16
#define TRACK2_ITEMS 13
#define LAB_ITEMS 7
#define VILLAGE_ITEMS 7

#define DEBUG_MANUAL 1

#define DISPLAY_HEIGHT 64

/*================================================================*/
/* breaker definitions and structures */
/*================================================================*/

///#define BO_F1 font_5x7
///#define BO_F2 font_6x12
///#define BO_F3 font_8x13

#define BO_FP 4

#define BO_AREA_WIDTH 7
#define BO_AREA_HEIGHT 3

#define AREA_WIDTH 7
#define AREA_HEIGHT 3

#define BO_BRICK_WIDTH ( (int16_t)10 << BO_FP )
#define BO_BRICK_HEIGHT ( (int16_t)4 << BO_FP )

#define BRICK_WIDTH 10
#define BRICK_HEIGHT 4

#define BALL_START_X 1
#define BALL_START_Y 4

#define BALL_SIZE 3

#define BALL_SIZE_FP ( 3 << BO_FP )

#define BO_AREA_UNIT_X ( BO_BRICK_WIDTH + ( (int16_t)4 << BO_FP ) )
#define BO_AREA_UNIT_Y ( BO_BRICK_HEIGHT + ( (int16_t)4 << BO_FP ) )
#define BO_AREA_ORIG_X ( (int16_t)2 << BO_FP )
#define BO_AREA_ORIG_Y ( (int16_t)(DISPLAY_HEIGHT - 32) << BO_FP )

#define AREA_UNIT_X ( BRICK_WIDTH + 4 )
#define AREA_UNIT_Y ( BRICK_HEIGHT + 4 )
#define AREA_ORIG_X 2
#define AREA_ORIG_Y ( DISPLAY_HEIGHT - 32 )

/* dimensions of the overall game field (BO_FP units) */
#define BO_FIELD_WIDTH ( BO_AREA_ORIG_X + BO_AREA_UNIT_X * BO_AREA_WIDTH )
#define BO_FIELD_HEIGHT ( BO_AREA_ORIG_Y + BO_AREA_UNIT_Y * BO_AREA_HEIGHT )

#define FIELD_WIDTH ( AREA_ORIG_X + AREA_UNIT_X * AREA_WIDTH )
#define FIELD_HEIGHT ( AREA_ORIG_Y + AREA_UNIT_Y * AREA_HEIGHT )

#define PLAYER_Y0 1
#define PLAYER_Y1 3

#define PLAYER_Y0_FP ( PLAYER_Y0 << BO_FP )
#define PLAYER_Y1_FP ( PLAYER_Y1 << BO_FP )

#define PLAYER_WIDTH 22
#define PLAYER_HEIGHT 3

#define PLAYER_WIDTH_FP ( PLAYER_WIDTH  << BO_FP )
#define PLAYER_HEIGHT_FP ( PLAYER_HEIGHT << BO_FP )

#define PLAYER_MAX_X FIELD_WIDTH - PLAYER_WIDTH + 2 //um
#define PLAYER_MIN_X 2

#define PLAYER_MAX_X_FP ( PLAYER_MAX_X << BO_FP )
#define PLAYER_MIN_X_FP ( PLAYER_MIN_Y << BO_FP )

#define PLAYER_X_ACCELERATION_FP ( 1 << ( BO_FP - 2 ) )
#define PLAYER_MAX_X_VELOCITY_FP ( 2 << BO_FP )

/* pixel values */
#define BO_FIELD_X0 2
#define BO_FIELD_Y0 2
#define BO_FIELD_X1 ( (uint8_t)( BO_FIELD_X0 + ( (BO_FIELD_WIDTH)>>BO_FP ) ) )
#define BO_FIELD_Y1 ( (uint8_t)( BO_FIELD_Y0 + ( (BO_FIELD_HEIGHT) >> BO_FP ) ) )
#define BO_FIELD_PIX_WIDTH ( (uint8_t)( (BO_FIELD_WIDTH) >> BO_FP ) )
#define BO_FIELD_PIX_HEIGHT ( (uint8_t)( (BO_FIELD_HEIGHT) >> BO_FP ) )

/* brick states */
#define BO_BRICK_NONE 0
#define BO_BRICK_NORMAL 1
#define BO_BRICK_SOLID 2
#define BO_BRICK_BALL 3




uint8_t uiKeyCodeFirst = KEY_NONE;
uint8_t uiKeyCodeSecond = KEY_NONE;
uint8_t uiKeyCode = KEY_NONE;
uint16_t uiIdleCount = 0;

struct bo_ball {
  int16_t dx;	/* fixed point 12.4 */
  int16_t dy;  /* fixed point 12.4 */
  int16_t x0;	/* fixed point 12.4 */
  int16_t x1;	/* fixed point 12.4 */
  int16_t y0;   /* fixed point 12.4 */
  int16_t y1;   /* fixed point 12.4 */
  int16_t lbr_x;	/* last brick reflection */
  int16_t lbr_y;	/* last brick reflection */
  unsigned is_ball_reflection;
  unsigned is_ball_lost;
};

bo_ball bo_ball1_obj;
bo_ball bo_ball2_obj;
bo_ball bo_ball3_obj;

struct bo_player
{
  int16_t w;	/* fixed point 12.4 */
  int16_t x0;	/* fixed point 12.4 */
  int16_t x1;	/* fixed point 12.4 */
  //int16_t y0;   /* fixed point 12.4 */
  //int16_t y1;   /* fixed point 12.4 */
  
  int16_t xv;
};

/*================================================================*/
/* breaker global variables */
/*================================================================*/
unsigned long next_sec_time;
uint8_t fps, frame_cnt;

byte bo_area[BO_AREA_HEIGHT][BO_AREA_WIDTH];
int16_t bo_player_brick_points; /* only written to... could  be removed */
int16_t bo_remaining_bricks;
int16_t bo_no_reflection_cnt = 0;

bo_player bo_player_obj;
uint8_t bo_step_state;
byte bo_timer;
byte bo_level;

#define BO_STATE_IN_GAME 1
#define BO_STATE_LOST 2
#define BO_STATE_RESTART 3
#define BO_STATE_COMPLETED 4
#define BO_STATE_INTRO 5
#define BO_STATE_INTRO1 6

#define DEFINED_LEVELS 4
#define L ( 1 + ( 3 << 2 ) )

 byte levels[][ 7 * 3 ] = { {  64,  84,  80, 209,  80,  84,  64,
                               64,  84,  68, 197,  68,  84,  64,
                               64, 213, 209, 209, 209, 213,  64 } };
                          /*{ 1, 1, 1, 1, 1, 1, 1,
                                1, 1, 1, 1, 1, 1, 1,
                                1, 1, 1, 1, 1, 1, 1 }, 
                              { 2, 2, 2, 2, 2, 2, 2,
                                2, 2, 2, 2, 2, 2, 2,
                                2, 2, 2, 2, 2, 2, 2 } };*/
                                
void bo_uiStep(void) {
  uint8_t is_key_pressed = 0;
  
  if ( digitalRead(uiKeyLeft) == LOW ) {
    is_key_pressed = 1;
    bo_player_obj.xv = max( -PLAYER_MAX_X_VELOCITY_FP, bo_player_obj.xv - PLAYER_X_ACCELERATION_FP );
  }
  
  if ( digitalRead(uiKeyRight) == LOW ) {
    is_key_pressed = 1;
    bo_player_obj.xv = min( PLAYER_MAX_X_VELOCITY_FP, bo_player_obj.xv + PLAYER_X_ACCELERATION_FP );
  }
    if ( digitalRead(uiKeyPrev) == LOW ) {
    is_key_pressed = 1;
  }
  
  if ( digitalRead(uiKeyNext) == LOW ) {
    is_key_pressed = 1;
  }
  
  if ( is_key_pressed == 0 ) {
    if ( bo_player_obj.xv > 0 ) {
      bo_player_obj.xv -= PLAYER_X_ACCELERATION_FP;
    } else if ( bo_player_obj.xv < 0 ) {
      bo_player_obj.xv += PLAYER_X_ACCELERATION_FP;
    }
  }
}

void bo_loop() {
  bo_Setup(0);
  while (bo_step_state != BO_STATE_LOST)
  {
    u8g.firstPage();
  
    do {
      bo_Draw();
      bo_DrawFPS(fps);
    } while( u8g.nextPage() );
  
    bo_uiStep();
    bo_SetPlayerPos( &bo_player_obj );
    bo_Step();
  }  
  u8g.firstPage();
  
    do {
      bo_Draw();
      bo_DrawFPS(fps);
    } while( u8g.nextPage() );
  
   EEPROM.write(SCORE_BYTE,bo_player_brick_points);
}

/*================================================================*/
/* Breakers APIs */
/*================================================================*/

void bo_Draw() {
    char points[45];
    draw_bricks();
    draw_ball(&bo_ball1_obj);
    draw_ball(&bo_ball2_obj);
    draw_ball(&bo_ball3_obj);
    draw_player(&bo_player_obj);
    ///draw_field(bo_level);
    
    
    if ( bo_step_state == BO_STATE_INTRO1 )
    {
      u8g.setRot180();
      u8g.drawStrP(20,4*L_FONT_HEIGHT, (const u8g_pgm_uint8_t*)PSTR("THOTCON 0x5"));
      u8g.undoRotation();
      
    }
    if ( bo_step_state == BO_STATE_LOST )
    {
      itoa(bo_player_brick_points , points, 10);
      u8g.setRot180();
      u8g.drawStrP(24,3*L_FONT_HEIGHT, (const u8g_pgm_uint8_t*)PSTR("GAME OVER"));
      u8g.drawStrP(24,4*L_FONT_HEIGHT, (const u8g_pgm_uint8_t*)PSTR("SCORE: "));
      u8g.drawStr(70,4*L_FONT_HEIGHT, points);
      u8g.undoRotation();
    }
    if ( bo_step_state == BO_STATE_COMPLETED )
    {

      u8g.setRot180();
      u8g.drawStrP(24,4*L_FONT_HEIGHT, (const u8g_pgm_uint8_t*)PSTR("COMPLETE!"));
      u8g.undoRotation();
    }
    
}

void bo_Step(void) {
  if ( bo_no_reflection_cnt >= 3 ) {
    bo_no_reflection_cnt-=3;
  }
  else {
    bo_no_reflection_cnt=0;
  }
  
  switch(bo_step_state) {
    case BO_STATE_INTRO:
      bo_step_state = BO_STATE_INTRO1;
      bo_timer = 80;
      break;
    case BO_STATE_INTRO1:
      bo_timer--;
      if ( bo_timer == 0 ) {
        bo_step_state = BO_STATE_IN_GAME;
      }
      break;
    case BO_STATE_IN_GAME:
      bo_DoBallStep( &bo_ball1_obj, &bo_player_obj );
      bo_DoBallStep( &bo_ball2_obj, &bo_player_obj );
      bo_DoBallStep( &bo_ball3_obj, &bo_player_obj );
      
      if ( bo_ball1_obj.is_ball_lost != 0 && bo_ball2_obj.is_ball_lost != 0  && bo_ball3_obj.is_ball_lost != 0 ) {
        bo_step_state = BO_STATE_LOST;
        bo_timer = 80;
      }
        
      bo_CalcRemainingBricks();
      
      if ( bo_remaining_bricks == 0 
           #if defined(DEBUG)
           || digitalRead(uiKeySelect) == LOW
           #endif 
           ) {
        bo_step_state = BO_STATE_COMPLETED;
        bo_timer = 80;
      }
      break;
    case BO_STATE_LOST:
      bo_timer--;
      if ( bo_timer == 0 ) {
        bo_step_state = BO_STATE_RESTART;
      }
      break;
    case BO_STATE_RESTART:
      bo_step_state = BO_STATE_IN_GAME;
      bo_Setup(0);
      break;
    case BO_STATE_COMPLETED:
      bo_timer--;
      if ( bo_timer == 0 ) {
        bo_step_state = BO_STATE_IN_GAME;
        bo_Setup( bo_level + 1 );
      }
  }
}

void bo_Setup(uint8_t level) {
  /* level = 4; */
  bo_no_reflection_cnt = 0;
  bo_level = level;
  bo_SetupBall(&bo_ball1_obj);
  bo_SetupBall(&bo_ball2_obj);
  bo_ball2_obj.is_ball_lost = 1;
  bo_SetupBall(&bo_ball3_obj);
  bo_ball3_obj.is_ball_lost = 1;
  bo_SetupPlayer(&bo_player_obj);
  bo_SetupLevel(level);
  if ( level == 0 )
    bo_step_state = BO_STATE_INTRO;
  else
    bo_step_state = BO_STATE_IN_GAME;
}

/*================================================================*/
/* setup */
/*================================================================*/

void bo_CalcRemainingBricks() {
  int w, h;
  int x, y;
  
  bo_remaining_bricks = 0;
  w = BO_AREA_WIDTH;
  h = BO_AREA_HEIGHT;
  
  for( y = 0; y < h; y++ ) {
    for( x = 0; x < w; x++ ) {
      if ( bo_area[y][x] == BO_BRICK_NORMAL || bo_area[y][x] == BO_BRICK_BALL )
	bo_remaining_bricks++;
    }
  }
}

void bo_SetupLevel( uint8_t level ) {
  int x, y;
  byte levelActual = level % DEFINED_LEVELS;
  byte shift = levelActual * 2;
  byte index = ( levelActual - ( levelActual % 4 ) ) / 4;
  
  for( y = 0; y < BO_AREA_HEIGHT; y++ ) {
    for( x = 0; x < BO_AREA_WIDTH; x++ ) {
      bo_area[y][x] = ( levels[index][ x + y * 7 ] >> shift ) & 3;
    }
  }
}

void bo_SetupBall( struct bo_ball *b ) {
  b->dx = ( 1 << BO_FP ) / 2;
  b->dy = ( 1 << BO_FP ) / 2;
  b->x0 = ( 1 << BO_FP );
  b->y0 = ( 1 << BO_FP ) + 2 * ( 1 << BO_FP );
  b->x1 = 5 * ( 1 << BO_FP );
  b->y1 = 5 * ( 1 << BO_FP ) + 2 * ( 1 << BO_FP );
  
  b->lbr_x = -1;
  b->lbr_y = -1;
  
  b->is_ball_lost = 0;
  b->is_ball_reflection = 0;
}

/* pos is between 0 and 255 */
void bo_SetPlayerPos( struct bo_player *p  ) {
  uint8_t tmp;
  
  //tmp = ( ( BO_FIELD_WIDTH - p->w - BO_FP ) >> BO_FP ) ;
  //tmp = (uint8_t)( ( (uint16_t)tmp * (uint16_t)pos ) / 255 );
  //p->x0 = ( (int16_t)tmp ) << BO_FP;
  //p->x1 = p->x0 + p->w;
  
  p->x0 = max( min( p->x0 + p->xv, PLAYER_MAX_X_FP ), 0 ) ;
  p->x1 = p->x0 + PLAYER_WIDTH_FP;
}

void bo_SetupPlayer( struct bo_player *p ) {
  p->w = PLAYER_WIDTH_FP; //(int16_t)22 * (int16_t)( 1 << BO_FP );
  ///bo_SetPlayerPos( p, 128 );
}

/*================================================================*/
/* graphics */
/*================================================================*/

void draw_bricks() {
  int x, y;
  int fx, fy;
  
  for( y = 0; y < BO_AREA_HEIGHT; y++ ) {
    for( x = 0; x < BO_AREA_WIDTH; x++ ) {
      fx = BO_AREA_ORIG_X + x * BO_AREA_UNIT_X;
      fy = BO_AREA_ORIG_Y + y * BO_AREA_UNIT_Y;
      fx >>= BO_FP;
      fy >>= BO_FP;
      fx += BO_FIELD_X0;
      fy += BO_FIELD_Y0;
      draw_brick(fx, fy, bo_area[y][x]);
    }
  }
}

void draw_brick(uint8_t ox, uint8_t oy, uint8_t brick_status) {
  int w = BRICK_WIDTH;
  int h = BRICK_HEIGHT;
  
  switch(brick_status) {
    case BO_BRICK_NORMAL:
      u8g.drawBox( ox, oy, w, h );
      return;
    case BO_BRICK_SOLID:
      u8g.drawBox( ox, oy, w, h );
      u8g.setColorIndex(0);
      u8g.drawBox( ox + 1, oy + 1, w - 2, h - 2 );
      u8g.setColorIndex(1);
      return;
    case BO_BRICK_BALL:
      u8g.drawBox( ox, oy, w, h );
      u8g.setColorIndex(0);
      u8g.drawVLine( ox + 2, oy + 1, oy + 3 );
      u8g.drawPixel( ox + 1, oy + 2 );
      u8g.drawPixel( ox + 3, oy + 2 );
      u8g.setColorIndex(1);
      return;
    default:
      return;
  }
}

void draw_ball( struct bo_ball *b ) {
  if ( b->is_ball_lost )
    return;
  
  u8g.drawBox( ( b->x0 >> BO_FP ) + BO_FIELD_X0, ( b->y0 >> BO_FP ) + BO_FIELD_Y0, BALL_SIZE, BALL_SIZE );
}

void draw_player( struct bo_player *p ) {
  uint8_t ox, oy, w, h;
  
  ox = ( p->x0 >> BO_FP ) + BO_FIELD_X0;
  oy = ( PLAYER_Y0 ) + BO_FIELD_Y0;
  
  u8g.drawBox( ox, oy, PLAYER_WIDTH, PLAYER_HEIGHT );
}

void bo_DrawFPS( uint8_t fps ) {
  if ( fps > 0 ) {
    ///dog_DrawStr(85, DOG_HEIGHT-8, BO_F1, dog_itoa(fps));
  }
}

void draw_field( uint8_t level ) {
  uint8_t x;
  
  ///dog_SetVLine(BO_FIELD_X0, BO_FIELD_Y0, BO_FIELD_Y1);
  ///dog_SetVLine(BO_FIELD_X1-1, BO_FIELD_Y0, BO_FIELD_Y1);
  ///x = dog_DrawStr(4, DOG_HEIGHT-8, BO_F1, dog_itoa(bo_remaining_bricks));
  ///x = dog_DrawStrP(25, DOG_HEIGHT-8, BO_F1, DOG_PSTR("level"));
  ///dog_DrawStr(x+2+25, DOG_HEIGHT-8, BO_F1, dog_itoa(level+1));

  if ( bo_no_reflection_cnt > 0 ) {
    ///dog_DrawStr(x+2+25+15, DOG_HEIGHT-8, BO_F1, dog_itoa((bo_no_reflection_cnt>>8)+1));
  }
}

/*================================================================*/
/* aux functions */
/*================================================================*/

uint8_t bo_IsIntersection( int16_t a_min, int16_t a_max, int16_t b_min, int16_t b_max) {
  if ( a_max < b_min )
    return 0;
  if ( a_min > b_max )
    return 0;
  return 1;
}

uint8_t bo_IsBallIntersection( struct bo_ball *b, int16_t x0, int16_t x1, int16_t y0, int16_t y1 ) {
  if ( b->is_ball_lost )
    return 0;
  if ( bo_IsIntersection( b->x0, b->x1, x0, x1 ) == 0 )
    return 0;
  if ( bo_IsIntersection( b->y0, b->y1, y0, y1 ) == 0 )
    return 0;
  return 1;
}

/*================================================================*/
/* intersection and reflection */
/*================================================================*/

/*===== brick and area intersection =====*/

/*
  test versus brick at position (x,y) [12.4]
  (x,y) is the lower left point of the brick
*/
uint8_t bo_IsBallBrickIntersection( struct bo_ball *b, int16_t x, int16_t y ) {
  return bo_IsBallIntersection( b, x, x + BO_BRICK_WIDTH, y, y + BO_BRICK_HEIGHT );
}

/* (x,y) is the lower left point of the brick */
void bo_DoBallBrickReflection( struct bo_ball *b, int16_t x, int16_t y ) {
  int16_t mx, my;
  
  if ( b->lbr_x == x && b->lbr_y == y )
    return;

  /* calculate middle of the ball */
  mx = ( b->x0 + b->x1 ) / 2;
  my = ( b->y0 + b->y1 ) / 2;
  
  if ( mx >= x && mx <= x + BO_BRICK_WIDTH ) {
    /* top/bottom or edge reflection */
    if ( my >= y && my <= y + BO_BRICK_HEIGHT ) {
      /* edge reflection */
      b->dx = - b->dx;
      b->dy = - b->dy;      
      b->is_ball_reflection = 1;
    } else {
      /* top/bottom or edge reflection */
      b->dy = - b->dy;      
      b->is_ball_reflection = 1;
    }
  } else {
    /* must be left or right reflection */
    b->dx = - b->dx;
    b->is_ball_reflection = 1;
  }
  
  b->lbr_x = x;
  b->lbr_y = y;
}

/* check area for the specified ball */
void bo_CheckBrickArea( struct bo_ball *b ) {
  int16_t gx;
  int16_t gy;
  uint8_t ix;
  uint8_t iy;
  uint8_t is_reflect = 0;
  
  gy = BO_AREA_ORIG_Y;
  iy = 0;
  
  while( iy < BO_AREA_HEIGHT ) {
    gx = BO_AREA_ORIG_X;
    ix = 0;
    while( ix < BO_AREA_WIDTH ) {
      switch ( bo_area[iy][ix] ) {
	case BO_BRICK_NORMAL:
	case BO_BRICK_SOLID:
	  if ( is_reflect == 0 )
	    if ( bo_IsBallBrickIntersection( b, gx, gy ) ) {
	      //if ( bo_area[iy][ix] == BO_BRICK_NO_REFLECTION )
		//bo_no_reflection_cnt = 9*256;
	      if ( bo_no_reflection_cnt == 0 ) {
		bo_DoBallBrickReflection( b, gx, gy );
		is_reflect = 1;
	      }
	      bo_player_brick_points++;
	      if ( bo_area[iy][ix] != BO_BRICK_SOLID ) {
		bo_area[iy][ix] = BO_BRICK_NONE;
	      }
	    }
	  break;
	case BO_BRICK_BALL:
	  if ( is_reflect == 0 )
	    if ( bo_IsBallBrickIntersection(b, gx, gy) ) {
	      bo_ball *bb;
	      /* look for lost ball */
	      if ( bo_ball1_obj.is_ball_lost != 0 )
		bb = &bo_ball1_obj;
	      else if ( bo_ball2_obj.is_ball_lost != 0 )
		bb = &bo_ball2_obj;
	      else if ( bo_ball3_obj.is_ball_lost != 0 )
		bb = &bo_ball3_obj;
	      else
		  bb = NULL;
	      if ( bb != NULL )
		*bb = *b;		/* clone the ball */
	      /* reflection only applies to the original ball */
	      bo_DoBallBrickReflection(b, gx, gy);
	      is_reflect = 1;
	      bo_player_brick_points++;
	      bo_area[iy][ix] = BO_BRICK_NONE;
	      return;
	    }
	  break;
	default:
	  break;
      }
      gx += BO_AREA_UNIT_X;
      ix++;
    }
    gy += BO_AREA_UNIT_Y;
    iy++;
  }  
}

/*===== field intersection =====*/

void bo_CheckField(bo_ball *b) {
  uint8_t is_reflection = 0;
  
  if ( b->x0 <= 0 ) {
    b->dx = -b->dx;
    is_reflection = 1;
  }
  if ( b->x1 >= BO_FIELD_WIDTH ) {
    b->dx = -b->dx;
    is_reflection = 1;
  }
  if ( b->y0 <= 0 ) {
    b->is_ball_lost = 1;
    b->dy = -b->dy;
    is_reflection = 1;
  }
  if ( b->y1 >= BO_FIELD_HEIGHT ) {
    b->dy = -b->dy;
    is_reflection = 1;
  }
  if ( is_reflection != 0 ) {
    b->is_ball_reflection = 1;
    /* reset last brick reflection */
    b->lbr_x = -1;
    b->lbr_y = -1;
  }
}

/*===== player intersection =====*/

uint8_t bo_IsBallPlayerIntersection( struct bo_ball *b, struct bo_player *p ) {
  if ( b->is_ball_lost )
    return 0;
  if ( bo_IsIntersection( b->x0, b->x1, p->x0, p->x1 ) == 0 )
    return 0;
  if ( bo_IsIntersection( b->y0, b->y1, PLAYER_Y0_FP, PLAYER_Y1_FP ) == 0 )
    return 0;
  return 1;
}

void bo_DoBallPlayerReflection( struct bo_ball *b, struct bo_player *p ) {
  int16_t mx, my;
  int16_t x;
  
  if ( b->is_ball_lost )
    return;

  /* reset last brick reflection */
  b->lbr_x = -1;
  b->lbr_y = -1;  
  
  /* calculate middle of the ball */
  mx = ( b->x0 + b->x1 ) / 2;
  my = ( b->y0 + b->y1 ) / 2 ;
  if ( mx >= p->x0 && mx <= p->x1 ) {
    /* top/bottom or edge reflection */
    if ( my >= PLAYER_Y0_FP && my <= PLAYER_Y1_FP ) {
      /* edge reflection */
      b->dx = - b->dx;
      b->dy = - b->dy;
      b->is_ball_reflection = 1;
    } else {
      /* top/bottom or edge reflection */
      
      b->dy = - b->dy;
      
      /* reduce dx, depending on how far the middle of the player paddle was hit */ 
      x = ( p->x1 + p->x0 ) / 2;
      x = x - mx;
      
      /* x can be between 0 an (p->w <<BO_FP)/2 */
      /* normalize x to 2<<(BO_FP)/2 */
      x /= p->w >> BO_FP;

      b->dx = -x;
      
      b->is_ball_reflection = 1;
    }
  } else {
    /* must be left or right reflection */
    b->dx = - b->dx;
    b->is_ball_reflection = 1;
  }
}

void bo_CheckPlayer( struct bo_ball *b, struct bo_player *p ) {
  if ( bo_IsBallPlayerIntersection(b, p) != 0 ) {
    bo_DoBallPlayerReflection(b, p);
  }
}

/*================================================================*/
/* handle a single ball */
/*================================================================*/

void bo_DoDeltaLimit( struct bo_ball *b ) { 
  if ( b->dx >= ( 1 << BO_FP ) ) {
    b->dx = ( 1 << BO_FP );
  }
  
  if ( b->dy >= ( 1 << ( BO_FP - 1 ) ) ) {
    b->dy = ( 1 << ( BO_FP - 1 ) );
  }
  
  if ( b->dy == 0 ) {
    b->dy = -( 1 << ( BO_FP - 1 ) );
    bo_DoBallDelta(b);
  }
}

void bo_DoBallDelta( struct bo_ball *b ) {
  b->x0 += b->dx;
  b->x1 += b->dx;
  b->y0 += b->dy;
  b->y1 += b->dy;
}
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
void loop() {  

  uiStep();                  // check for key press
  if (uiKeyCode == KEY_NONE)
  {
         uiIdleCount++;
         delay(IDLE_MS); // wait a very short period to help calculate idleness  
  }
  else {
    uiIdleCount = 0;
  }
  if (uiIdleCount > IDLE_SCALE ) //idle > 30 sec
  {
    u8g.undoRotation();
    u8g.setColorIndex(1);
    draw_icon(icon);
    u8g.setRot180();
     uiIdleCount = 0;
     
    EEPROM.write(IDLE_BYTE,0x0);
    set_sleep_mode(SLEEP_MODE_PWR_DOWN);
    sleep_enable();
    sleep_cpu();
    sleep_disable();
    uiIdleCount = 0;
  }
  
  if (  menu_redraw != 0 ) {
 
      menu_state();
  } 
  menu_redraw = 0;
  

  updateMenu();                            // update menu bar
  /*#if defined (DEBUG)
  Serial.print("Idle: ");Serial.println(uiIdleCount);
  #endif
  */
}

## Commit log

2014-02-12 proto type code and schematics
2014-03-05 added realease package. -R-
    [thotcon_0x5_BOM_BY_REF.ods, thotcon_0x5_BOM_BY_REF.xls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]
2014-03-18 THOTCON0x5 Badge Project Hardware Initial commit: Mar 18 2014 Paul Reich
    Current revision: Issue T1
    Issue P1 in progress
    [thotcon_0x5-B_Mask.gbs, thotcon_0x5-B_Paste.gbp, thotcon_0x5-B_SilkS.gbo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]
2014-03-19 UUGear Raspberry Pi & Arduino connections
    Every Arduino assigns itself a random id. The Raspi side has a daemon that
    waits for USB connections, then asks the Arduino what it's id is. Commands
    can be sent to the correct Arduino no matter which USB port it uses.
2014-03-31 March 31 2014 Paul Reich <reichp@att.net>
    ChangeLog - RELEASE Issue P1 Hardware
    DELETES:
    00PCB-Layout: Replaced by "hardware"
    prior_art: Delete - no longer relevant.
    release: Delete. Previous version T1 now in the "attic".
    ADDS:
    hardware/development:
    Everything pertaining to the current version.
    hardware/development/iss_*:
    KiCad data files.
    hardware/development/iss_*/release:
    PDF copies of gerbers, BOM,etc.
    hardware/development/iss_*/release/fab:
    Manufacturing info & files.
    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
    [thotcon_0x5-B_Mask.gbs, thotcon_0x5-B_Paste.gbp, thotcon_0x5-B_SilkS.gbo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]
2014-04-01 Apr 1 2014 Paul Reich
    ANGES:
    Move R14 (2.2K TH) from add-on kit to production; USB needed on all models.
    DELETIONS:
    prototype directory: Schematic obsolete. Refer instead to
    hardware/development/iss_P1/release/thotcon_0x5_SCHEM-*.pdf
    [thotcon_0x5.csv, thotcon_0x5.sch, thotcon_0x5_BOM_BY_REF.ods]
2014-04-01 Apr 01 2014 Paul Reich
    - Release Thocon badge assembly package.
    [thotcon_0x5.brd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]
2014-04-05 Apr 4 2014 Paul Reich
    -- Add alternate pushbutton switches to library.
    -- Remove FDN340P FET datasheet from library - we won't be
    using it.
2014-04-11 April 11 2014 Paul Reich
    Update schmatic/PCB information for pushbutton switches S1-S7. Do not
    require the use of white display backing tape for certain silkscreen
    colors (made possible by the use of a white-backed display).
    Update assembly drawings and instructions accordingly.
    Paul Reich
    [thotcon_0x5.brd, thotcon_0x5.csv, thotcon_0x5.sch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]
2014-04-23 Raspberry infrastructure code
2014-04-23 current final
2014-04-24 Fixes to clean up Linux compile.
    [sleepfinal.ino]
2014-04-24 Updated link to flip during party, added scripts
    [sleepfinal.ino]
2014-04-24 Updated key bindings, added player selection.
    [sleepfinal.ino]
